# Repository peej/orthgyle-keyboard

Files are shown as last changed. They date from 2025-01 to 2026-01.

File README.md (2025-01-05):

# Orthgyle - Ortholinear keyboard PCB for the Argyle

Orthgyle is a 5x15 ortholinear PCB using through-hole components for the [Argyle keyboard](https://geekhack.org/index.php?topic=116274).

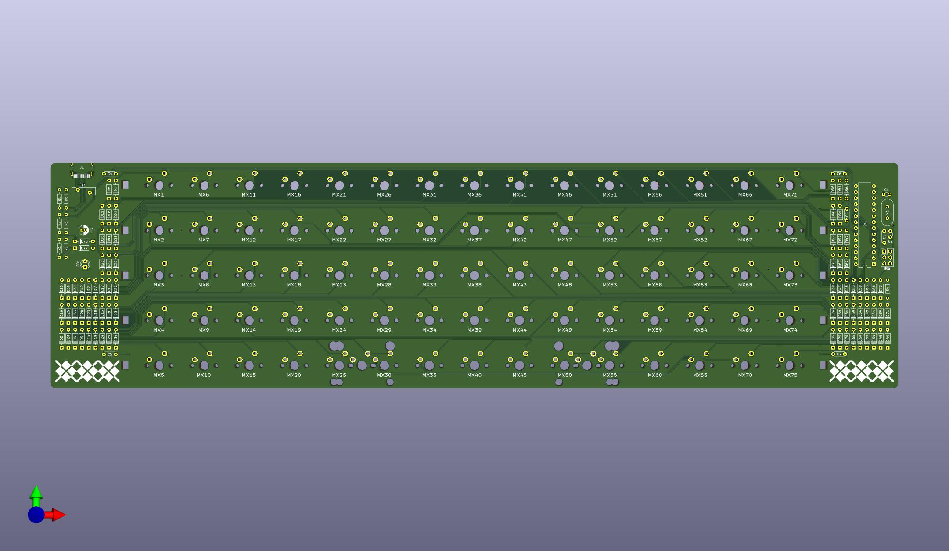
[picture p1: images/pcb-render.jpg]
PCB render


* Designed to be a drop in replacement for the standard staggered Argyle PCB.
* Same Atmega283p MCU and side panel LEDs
* Uses a [Japanese Matrix](https://kbd.news/The-Japanese-duplex-matrix-1391.html) instead of an IO expander to simplify components and firmware.

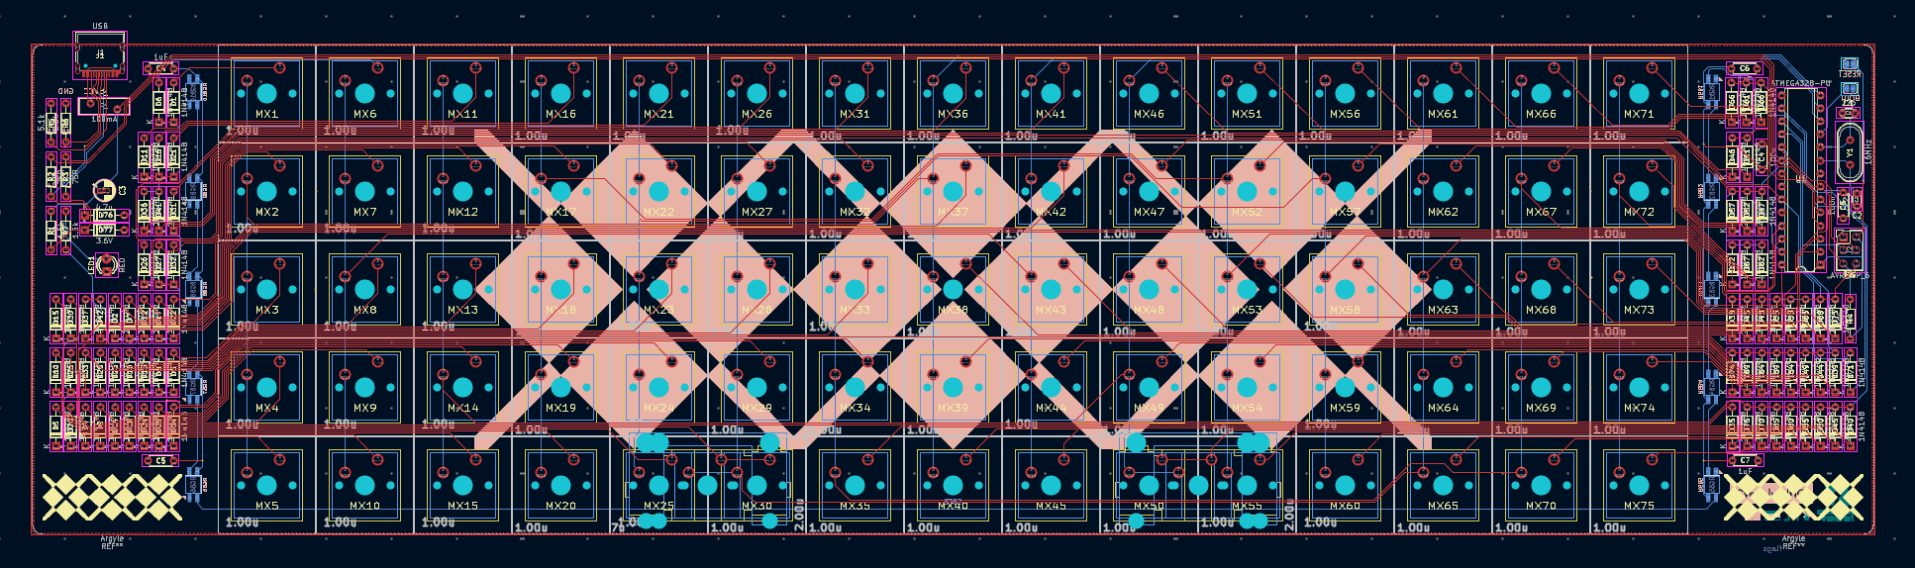
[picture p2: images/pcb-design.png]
PCB design


See the [Bill of materials](BOM.md) for a detailed list of the required parts.

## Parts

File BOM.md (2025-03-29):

# Bill of Materials (BOM)

| Ref | Qty | Value or Part# | Description |
|---|-----|---|---|
| C1,C2 | 2 | 22pF p2.5mm | multilayer ceramic capacitor |
| C3 | 1 | 4.7uF p1.5mm | electrolytic capacitor |
| C4,C5 | 2 | 100nF p5.0mm | multilayer ceramic capacitor |
| C6-9 | 4 | 1uF p5.0mm | multilayer ceramic capacitor |
| D1-75 | 75  | 1n4148 | diode |
| D61,D62 | 2 | 3.6V | zener diode |
| F1 | 1 | 100mA | polyfuse |
| J1 | 1 | TYPE-C-31-M-12 | USB-C connector |
| J2 | 1 | 2x3 p2.54mm | AVR ISP pin header (optional) |
| LED1 | 1 | 3mm | LED |
| MX1-75 | 75  | MX | keyboard switch |
| R1,R7 | 2 | 1.5kΩ | resistor |
| R2,R3 | 2 | 75Ω | resistor |
| R4 | 1 | 10kΩ | resistor |
| R5,R6 | 2 | 5.1kΩ | resistor |
| RGB1-10 | 10  | SK6812-mini-e  | intelligent control RGB LED |
| IC socket | 1 | 28pin narrow | IC socket |
| U1 | 1 | ATMEGA328P | microcontroller |
| Y1 | 1 | HC49-4H 16MHz  | crystal |

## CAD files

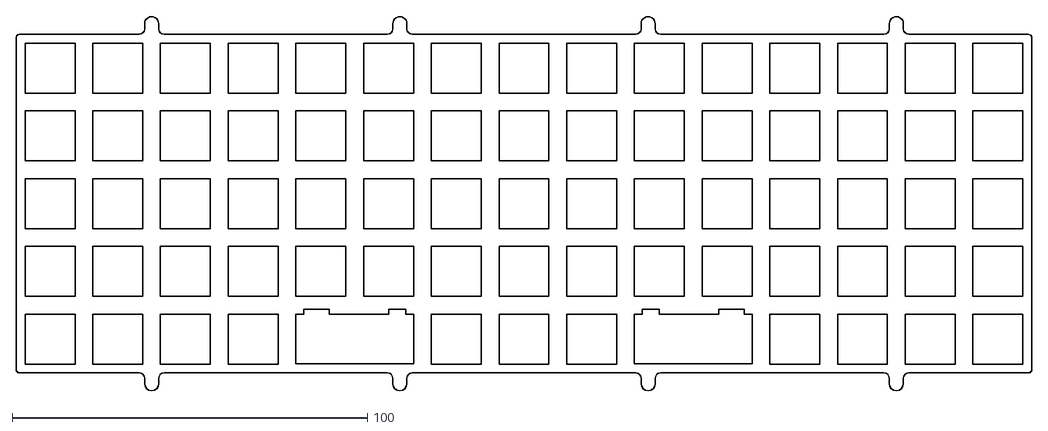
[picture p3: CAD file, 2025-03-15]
plate/orthgyle.dxf
285.8 x 105.3

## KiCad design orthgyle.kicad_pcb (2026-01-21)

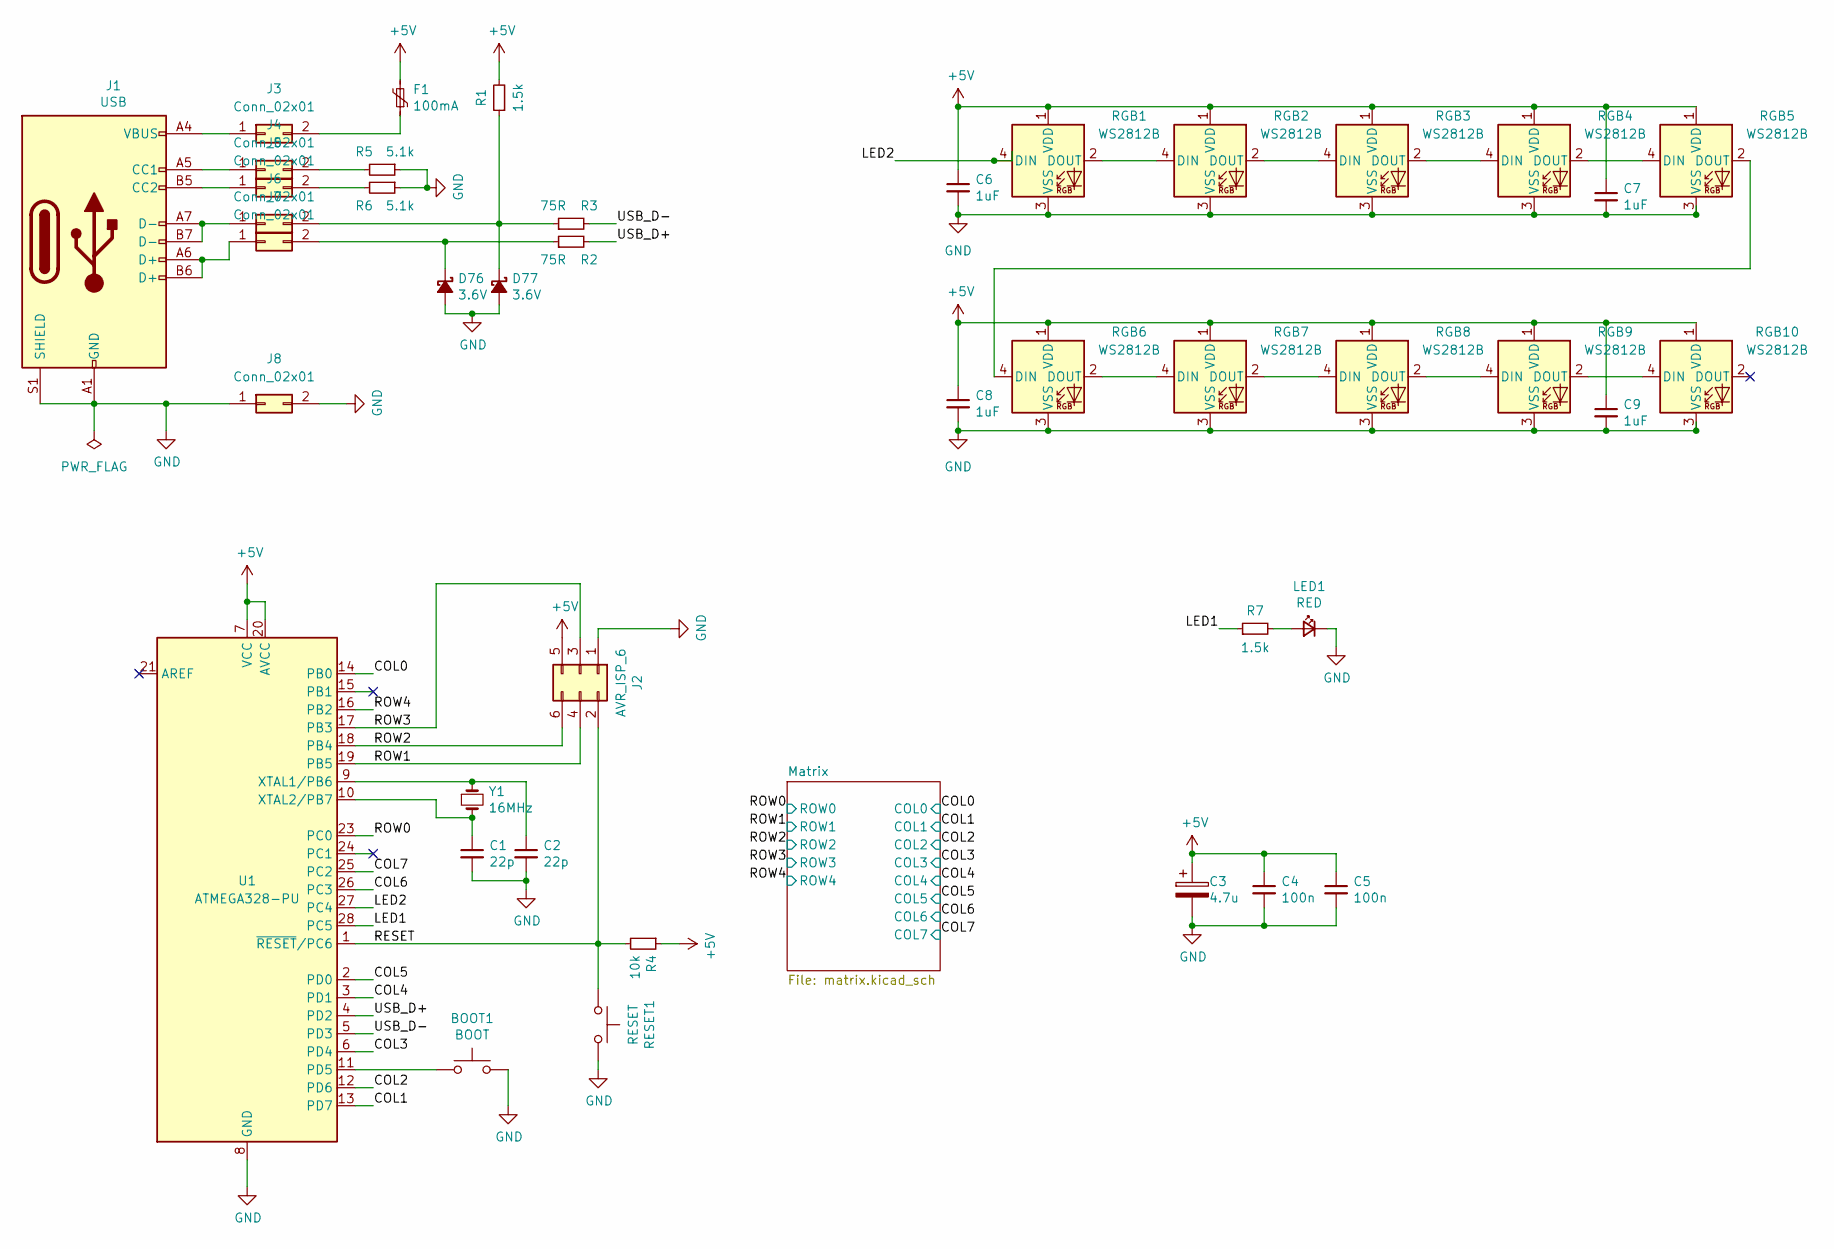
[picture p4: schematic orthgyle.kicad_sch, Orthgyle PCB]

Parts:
BOOT1: BOOT; SolderJumper-2_P1.3mm_Open_RoundedPad1.0x1.5mm
C1, C2: 22p; C_Disc_D3.0mm_W1.6mm_P2.50mm
C3: 4.7u; CP_Radial_D4.0mm_P1.50mm
C4, C5: 100n; C_Disc_D4.3mm_W1.9mm_P5.00mm
C6, C7, C8, C9: 1uF; C_Disc_D4.3mm_W1.9mm_P5.00mm
D76, D77: 3.6V; D_DO-35_SOD27_P7.62mm_Horizontal
F1: 100mA; Fuse_Bourns_MF-RHT100
J1: USB; USB_C_Receptacle_HRO_TYPE-C-31-M-12
J2: AVR_ISP_6; PinHeader_2x03_P2.54mm_Vertical
J3, J4, J5, J6, J7, J8: Conn_02x01; SolderJumper-2_P1.3mm_Bridged_RoundedPad1.0x1.5mm
LED1: RED; LED_D3.0mm
R1, R7: 1.5k; R_Axial_DIN0204_L3.6mm_D1.6mm_P7.62mm_Horizontal
R2, R3: 75R; R_Axial_DIN0204_L3.6mm_D1.6mm_P7.62mm_Horizontal
R4: 10k; R_Axial_DIN0204_L3.6mm_D1.6mm_P7.62mm_Horizontal
R5, R6: 5.1k; R_Axial_DIN0204_L3.6mm_D1.6mm_P7.62mm_Horizontal
RESET1: RESET; SolderJumper-2_P1.3mm_Open_RoundedPad1.0x1.5mm
RGB1, RGB2, RGB3, RGB4, RGB5, RGB6, RGB7, RGB8, RGB9, RGB10: WS2812B; SK6812-MINI-E
U1: ATMEGA328-PU; DIP-28_W7.62mm
Y1: 16MHz; Crystal_HC49-4H_Vertical

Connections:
+5V: C3.1, C4.1, C5.1, C6.1, C7.1, C8.1, C9.1, F1.2, J2.5, R1.2, R4.1, RGB1.1 (VDD), RGB2.1 (VDD), RGB3.1 (VDD), RGB4.1 (VDD), RGB5.1 (VDD), RGB6.1 (VDD), RGB7.1 (VDD), RGB8.1 (VDD), RGB9.1 (VDD), RGB10.1 (VDD), U1.7 (VCC), U1.20 (AVCC)
/COL0: U1.14 (PB0); also elsewhere on the board
/COL1: U1.13 (PD7); also elsewhere on the board
/COL2: U1.12 (PD6); also elsewhere on the board
/COL3: U1.6 (PD4); also elsewhere on the board
/COL4: U1.3 (PD1); also elsewhere on the board
/COL5: U1.2 (PD0); also elsewhere on the board
/COL6: U1.26 (PC3); also elsewhere on the board
/COL7: U1.25 (PC2); also elsewhere on the board
/LED1: R7.1, U1.28 (PC5)
/LED2: RGB1.4 (DIN), U1.27 (PC4)
/RESET: J2.2, R4.2, RESET1.1, U1.1 (~RESET/PC6)
/ROW0: U1.23 (PC0); also elsewhere on the board
/ROW1: J2.4, U1.19 (PB5); also elsewhere on the board
/ROW2: J2.6, U1.18 (PB4); also elsewhere on the board
/ROW3: J2.3, U1.17 (PB3); also elsewhere on the board
/ROW4: U1.16 (PB2); also elsewhere on the board
/USB_D+: R2.2, U1.4 (PD2)
/USB_D-: R3.2, U1.5 (PD3)
GND: BOOT1.2, C1.2, C2.2, C3.2, C4.2, C5.2, C6.2, C7.2, C8.2, C9.2, D76.2 (A), D77.2 (A), J1.A1 (GND), J1.A12 (GND), J1.B1 (GND), J1.B12 (GND), J1.S1 (SHIELD), J2.1, J8.1, J8.2, LED1.1 (K), R5.1, R6.1, RESET1.2, RGB1.3 (VSS), RGB2.3 (VSS), RGB3.3 (VSS), RGB4.3 (VSS), RGB5.3 (VSS), RGB6.3 (VSS), RGB7.3 (VSS), RGB8.3 (VSS), RGB9.3 (VSS), RGB10.3 (VSS), U1.8 (GND), U1.22 (GND)
unnamed: D76.1 (K), J7.2, R2.1
unnamed: D77.1 (K), J6.2, R1.1, R3.1
unnamed: J1.A5 (CC1), J4.1
unnamed: J1.B5 (CC2), J5.1
unnamed: J1.A4 (VBUS), J1.A9 (VBUS), J1.B4 (VBUS), J1.B9 (VBUS), J3.1
unnamed: F1.1, J3.2
unnamed: J4.2, R5.2
unnamed: J5.2, R6.2
unnamed: J1.A7 (D-), J1.B7 (D-), J6.1
unnamed: J1.A6 (D+), J1.B6 (D+), J7.1
unnamed: LED1.2 (A), R7.2
unnamed: RGB1.2 (DOUT), RGB2.4 (DIN)
unnamed: RGB2.2 (DOUT), RGB3.4 (DIN)
unnamed: RGB3.2 (DOUT), RGB4.4 (DIN)
unnamed: RGB4.2 (DOUT), RGB5.4 (DIN)
unnamed: RGB5.2 (DOUT), RGB6.4 (DIN)
unnamed: RGB6.2 (DOUT), RGB7.4 (DIN)
unnamed: RGB7.2 (DOUT), RGB8.4 (DIN)
unnamed: RGB8.2 (DOUT), RGB9.4 (DIN)
unnamed: RGB9.2 (DOUT), RGB10.4 (DIN)
unnamed: BOOT1.1, U1.11 (PD5)
unnamed: C2.1, U1.9 (XTAL1/PB6), Y1.1
unnamed: C1.1, U1.10 (XTAL2/PB7), Y1.2

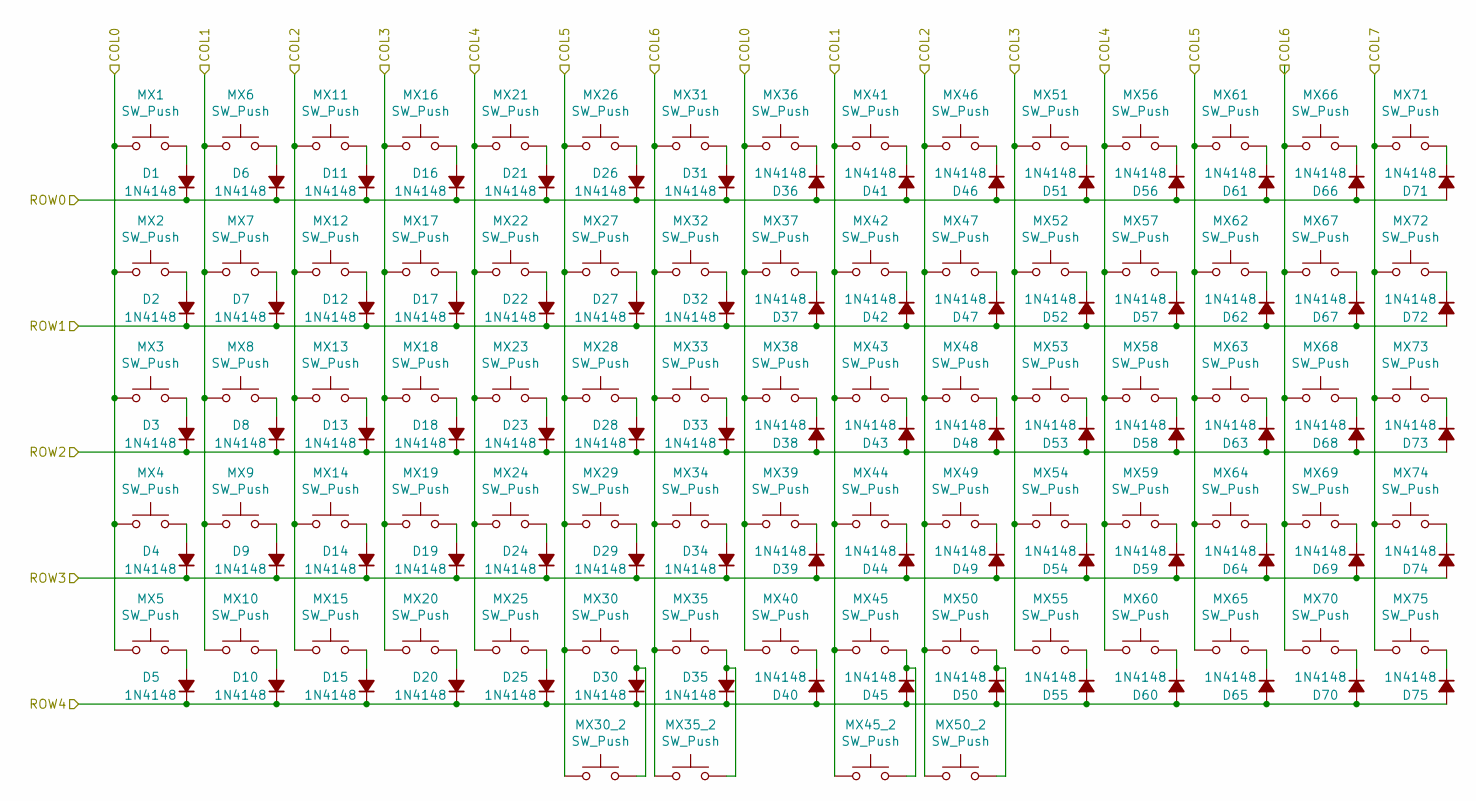
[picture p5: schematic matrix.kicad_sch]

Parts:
D1, D2, D3, D4, D5, D6, D7, D8, D9, D10, D11, D12, D13, D14, D15, D16, D17, D18, D19, D20, D21, D22, D23, D24, D25, D26, D27, D28, D29, D30, D31, D32, D33, D34, D35, D36, D37, D38, D39, D40, D41, D42, D43, D44, D45, D46, D47, D48, D49, D50, D51, D52, D53, D54, D55, D56, D57, D58, D59, D60, D61, D62, D63, D64, D65, D66, D67, D68, D69, D70, D71, D72, D73, D74, D75: 1N4148; D_DO-35_SOD27_P7.62mm_Horizontal
MX1, MX2, MX3, MX4, MX5, MX6, MX7, MX8, MX9, MX10, MX11, MX12, MX13, MX14, MX15, MX16, MX17, MX18, MX19, MX20, MX21, MX22, MX23, MX24, MX25, MX26, MX27, MX28, MX29, MX30, MX31, MX32, MX33, MX34, MX35, MX36, MX37, MX38, MX39, MX41, MX42, MX43, MX44, MX45, MX46, MX47, MX48, MX49, MX50, MX51, MX52, MX53, MX54, MX55, MX56, MX57, MX58, MX59, MX60, MX61, MX62, MX63, MX64, MX65, MX66, MX67, MX68, MX69, MX70, MX71, MX72, MX73, MX74, MX75: SW_Push; MX
MX30_2, MX35_2, MX45_2, MX50_2: SW_Push; MX_PCB_200H
MX40: SW_Push; MX_PCB_700H

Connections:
/COL0: MX1.2, MX2.2, MX3.2, MX4.2, MX5.2, MX36.2, MX37.2, MX38.2, MX39.2, MX40.2; also elsewhere on the board
/COL1: MX6.2, MX7.2, MX8.2, MX9.2, MX10.2, MX41.2, MX42.2, MX43.2, MX44.2, MX45.2, MX45_2.2; also elsewhere on the board
/COL2: MX11.2, MX12.2, MX13.2, MX14.2, MX15.2, MX46.2, MX47.2, MX48.2, MX49.2, MX50.2, MX50_2.2; also elsewhere on the board
/COL3: MX16.2, MX17.2, MX18.2, MX19.2, MX20.2, MX51.2, MX52.2, MX53.2, MX54.2, MX55.2; also elsewhere on the board
/COL4: MX21.2, MX22.2, MX23.2, MX24.2, MX25.2, MX56.2, MX57.2, MX58.2, MX59.2, MX60.2; also elsewhere on the board
/COL5: MX26.2, MX27.2, MX28.2, MX29.2, MX30.2, MX30_2.2, MX61.2, MX62.2, MX63.2, MX64.2, MX65.2; also elsewhere on the board
/COL6: MX31.2, MX32.2, MX33.2, MX34.2, MX35.2, MX35_2.2, MX66.2, MX67.2, MX68.2, MX69.2, MX70.2; also elsewhere on the board
/COL7: MX71.2, MX72.2, MX73.2, MX74.2, MX75.2; also elsewhere on the board
/ROW0: D1.1 (K), D6.1 (K), D11.1 (K), D16.1 (K), D21.1 (K), D26.1 (K), D31.1 (K), D36.2 (A), D41.2 (A), D46.2 (A), D51.2 (A), D56.2 (A), D61.2 (A), D66.2 (A), D71.2 (A); also elsewhere on the board
/ROW1: D2.1 (K), D7.1 (K), D12.1 (K), D17.1 (K), D22.1 (K), D27.1 (K), D32.1 (K), D37.2 (A), D42.2 (A), D47.2 (A), D52.2 (A), D57.2 (A), D62.2 (A), D67.2 (A), D72.2 (A); also elsewhere on the board
/ROW2: D3.1 (K), D8.1 (K), D13.1 (K), D18.1 (K), D23.1 (K), D28.1 (K), D33.1 (K), D38.2 (A), D43.2 (A), D48.2 (A), D53.2 (A), D58.2 (A), D63.2 (A), D68.2 (A), D73.2 (A); also elsewhere on the board
/ROW3: D4.1 (K), D9.1 (K), D14.1 (K), D19.1 (K), D24.1 (K), D29.1 (K), D34.1 (K), D39.2 (A), D44.2 (A), D49.2 (A), D54.2 (A), D59.2 (A), D64.2 (A), D69.2 (A), D74.2 (A); also elsewhere on the board
/ROW4: D5.1 (K), D10.1 (K), D15.1 (K), D20.1 (K), D25.1 (K), D30.1 (K), D35.1 (K), D40.2 (A), D45.2 (A), D50.2 (A), D55.2 (A), D60.2 (A), D65.2 (A), D70.2 (A), D75.2 (A); also elsewhere on the board
unnamed: D1.2 (A), MX1.1
unnamed: D2.2 (A), MX2.1
unnamed: D3.2 (A), MX3.1
unnamed: D4.2 (A), MX4.1
unnamed: D5.2 (A), MX5.1
unnamed: D6.2 (A), MX6.1
unnamed: D7.2 (A), MX7.1
unnamed: D8.2 (A), MX8.1
unnamed: D9.2 (A), MX9.1
unnamed: D10.2 (A), MX10.1
unnamed: D11.2 (A), MX11.1
unnamed: D12.2 (A), MX12.1
unnamed: D13.2 (A), MX13.1
unnamed: D14.2 (A), MX14.1
unnamed: D15.2 (A), MX15.1
unnamed: D16.2 (A), MX16.1
unnamed: D17.2 (A), MX17.1
unnamed: D18.2 (A), MX18.1
unnamed: D19.2 (A), MX19.1
unnamed: D20.2 (A), MX20.1
unnamed: D21.2 (A), MX21.1
unnamed: D22.2 (A), MX22.1
unnamed: D23.2 (A), MX23.1
unnamed: D24.2 (A), MX24.1
unnamed: D25.2 (A), MX25.1
unnamed: D26.2 (A), MX26.1
unnamed: D27.2 (A), MX27.1
unnamed: D28.2 (A), MX28.1
unnamed: D29.2 (A), MX29.1
unnamed: D30.2 (A), MX30.1, MX30_2.1
unnamed: D31.2 (A), MX31.1
unnamed: D32.2 (A), MX32.1
unnamed: D33.2 (A), MX33.1
unnamed: D34.2 (A), MX34.1
unnamed: D35.2 (A), MX35.1, MX35_2.1
unnamed: D36.1 (K), MX36.1
unnamed: D37.1 (K), MX37.1
unnamed: D38.1 (K), MX38.1
unnamed: D39.1 (K), MX39.1
unnamed: D40.1 (K), MX40.1
unnamed: D41.1 (K), MX41.1
unnamed: D42.1 (K), MX42.1
unnamed: D43.1 (K), MX43.1
unnamed: D44.1 (K), MX44.1
unnamed: D45.1 (K), MX45.1, MX45_2.1
unnamed: D46.1 (K), MX46.1
unnamed: D47.1 (K), MX47.1
unnamed: D48.1 (K), MX48.1
unnamed: D49.1 (K), MX49.1
unnamed: D50.1 (K), MX50.1, MX50_2.1
unnamed: D51.1 (K), MX51.1
unnamed: D52.1 (K), MX52.1
unnamed: D53.1 (K), MX53.1
unnamed: D54.1 (K), MX54.1
unnamed: D55.1 (K), MX55.1
unnamed: D56.1 (K), MX56.1
unnamed: D57.1 (K), MX57.1
unnamed: D58.1 (K), MX58.1
unnamed: D59.1 (K), MX59.1
unnamed: D60.1 (K), MX60.1
unnamed: D61.1 (K), MX61.1
unnamed: D62.1 (K), MX62.1
unnamed: D63.1 (K), MX63.1
unnamed: D64.1 (K), MX64.1
unnamed: D65.1 (K), MX65.1
unnamed: D66.1 (K), MX66.1
unnamed: D67.1 (K), MX67.1
unnamed: D68.1 (K), MX68.1
unnamed: D69.1 (K), MX69.1
unnamed: D70.1 (K), MX70.1
unnamed: D71.1 (K), MX71.1
unnamed: D72.1 (K), MX72.1
unnamed: D73.1 (K), MX73.1
unnamed: D74.1 (K), MX74.1
unnamed: D75.1 (K), MX75.1

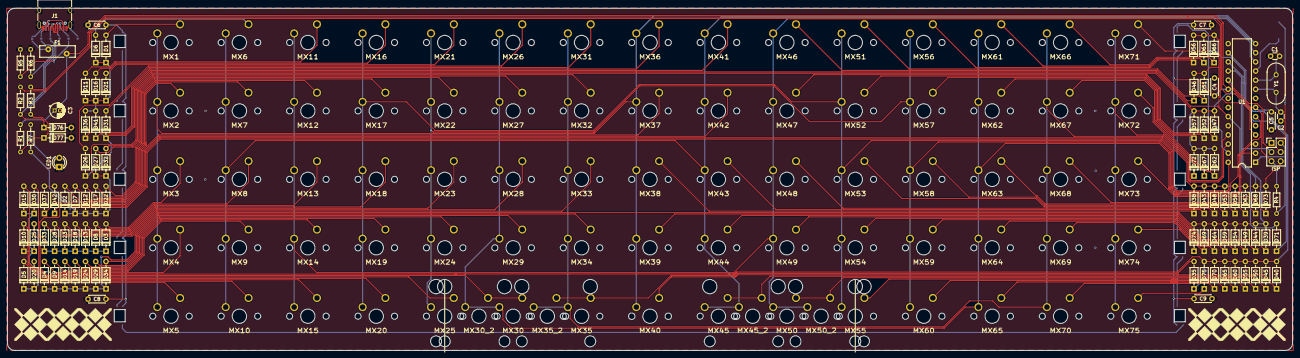
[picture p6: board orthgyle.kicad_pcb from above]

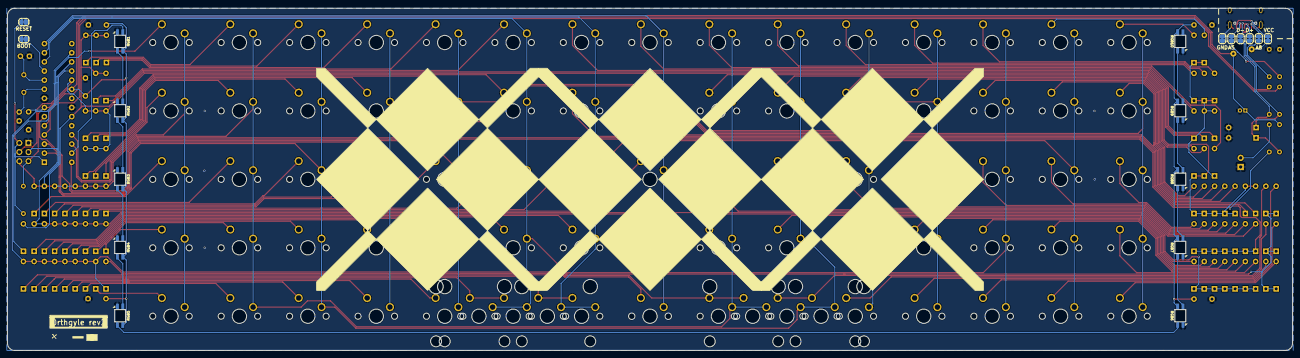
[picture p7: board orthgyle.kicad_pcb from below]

Board: 2 copper layers, 357.8 x 95.2 mm, 196 parts (18 on the bottom side), 118 nets.

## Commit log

2024-12-28 Add footprint files
2024-12-28 Add project files
    [matrix.kicad_sch, orthgyle.kicad_pcb, orthgyle.kicad_sch]
2024-12-28 Add plate project
    [plate.kicad_pcb]
2024-12-28 Add exported gerbers
    [orthgyle-B_Cu.gbr, orthgyle-B_Mask.gbr, orthgyle-B_Paste.gbr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]
2024-12-28 Update PCB page settings
    [orthgyle.kicad_pcb]
2024-12-29 Add stab cutouts to plate
    [plate.kicad_pcb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]
2024-12-29 Flip 2u stabilizers
    [matrix.kicad_sch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]
2025-01-04 Move decoupling capacitors closer to ICs
    [orthgyle-B_Cu.gbr, orthgyle-B_Mask.gbr, orthgyle-B_Paste.gbr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]
2025-01-05 Rename RGB diodes
    [orthgyle-B_Cu.gbr, orthgyle-B_Mask.gbr, orthgyle-B_Paste.gbr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]
2025-01-05 Add BOM
2025-03-13 Update plate file
    [plate.kicad_pcb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]
2025-03-15 Align USB port with case location
    Switch to SK6812 mini-e LEDs
    Flip stabilizer orientation
    [matrix.kicad_sch, orthgyle.kicad_pcb, orthgyle.kicad_sch]
2025-03-15 Update gerbers
    [orthgyle-B_Adhesive.gbr, orthgyle-B_Courtyard.gbr, orthgyle-B_Cu.gbr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]
2025-03-15 Add plate file DXF export
    [orthgyle.dxf]
2025-03-29 Switch LEDs to SK6812-mini-e
    [orthgyle.kicad_pcb, orthgyle.kicad_sch]
2025-03-29 Update BOM and images
2026-01-21 Add center offset 2u keys
    [matrix.kicad_sch, orthgyle.kicad_pcb, orthgyle.kicad_sch]
